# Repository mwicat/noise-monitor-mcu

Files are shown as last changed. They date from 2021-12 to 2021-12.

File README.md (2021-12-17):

# Noise level monitor using ESP8266 and InfluxDB

For server-side part of this project, see [noise-monitor-infra](https://github.com/mwicat/noise-monitor-infra)

<figure>
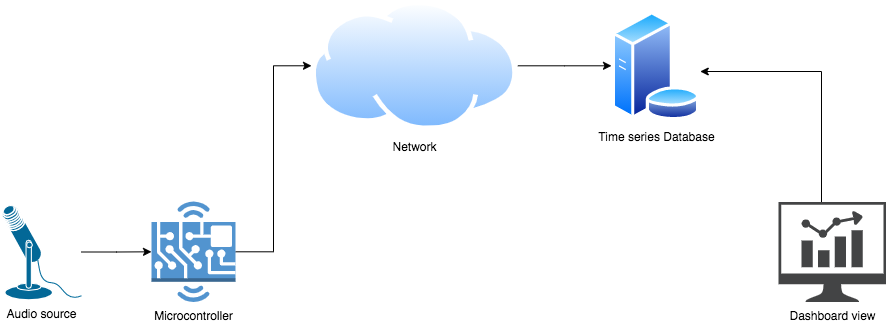
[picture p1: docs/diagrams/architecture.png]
High-level architecture

<figcaption>High-level architecture</figcaption>
</figure>

## How it works

- Monitors line level audio signal on TRS jack socket
- Transforms audio signal into volume envelope signal with
[Envelope detector circuit](https://en.wikipedia.org/wiki/Envelope_detector)
- [ESP8266 microcontroller](https://en.wikipedia.org/wiki/ESP8266) samples
envelope signal on analog input pin `A0`
- Visualises volume envelope by modulating blue LED brightness with PWM signal
on digital pin `D6`
- Converts amplitude to dB volume and sends to remote InfluxDB service
via Wi-fi connection
- On every successful write to InfluxDB service, the green LED connected to
digital pin `D5` will blink

<figure>
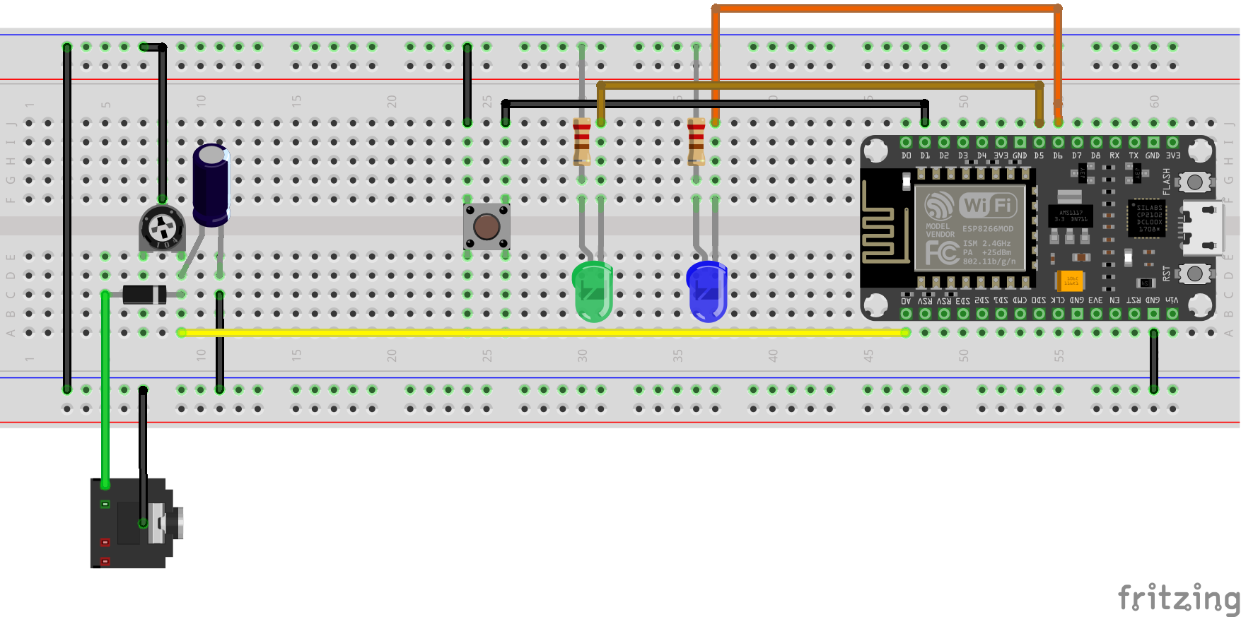
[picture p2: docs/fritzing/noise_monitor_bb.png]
Breadboard project

<figcaption>Breadboard project</figcaption>
</figure>

<figure>
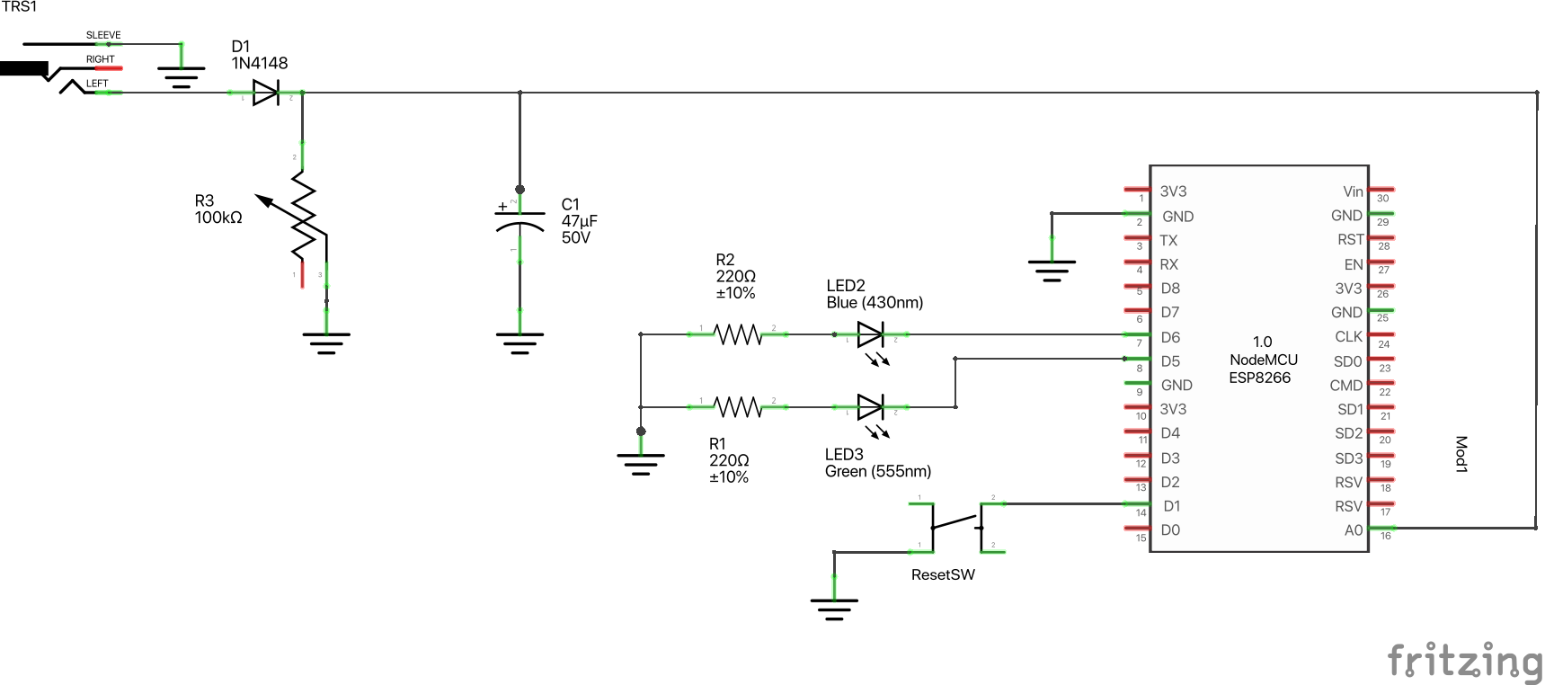
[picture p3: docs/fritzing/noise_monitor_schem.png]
Circuit schematic

<figcaption>Circuit schematic</figcaption>
</figure>

## Usage

1. Deploy attached firmware code to your MCU (project format is PlatformIO).
2. On first run MCU will start wireless access point with SSID 
3. Connect to wireless network `NoiseMonitorAP`. Default password is set
by `AP_PASSWORD` macro to `ohmynoize`
4. [Captive portal](https://en.wikipedia.org/wiki/Captive_portal) should appear
where you can configure credentials for Wi-fi that MCU should ultimately connect
to. Also specify settings for InfluxDB connection. For more details on how this
phase works or how it should work, see [WiFiManager documentation](https://github.com/tzapu/WiFiManager/blob/master/README.md#how-it-works)
5. After MCU successfuly connects to target Wi-fi network, captive portal
should disappear and builtin LED should light up
6. You can now connect audio to TRS socket. You can use headphone output
from your laptop or line out from [preamplifier](https://en.wikipedia.org/wiki/Microphone_preamplifier).
In my case I used line/headphone out from [Tascam DR-22WL
](https://www.tascam.eu/en/dr-22wl) handheld recorder.

<figure>
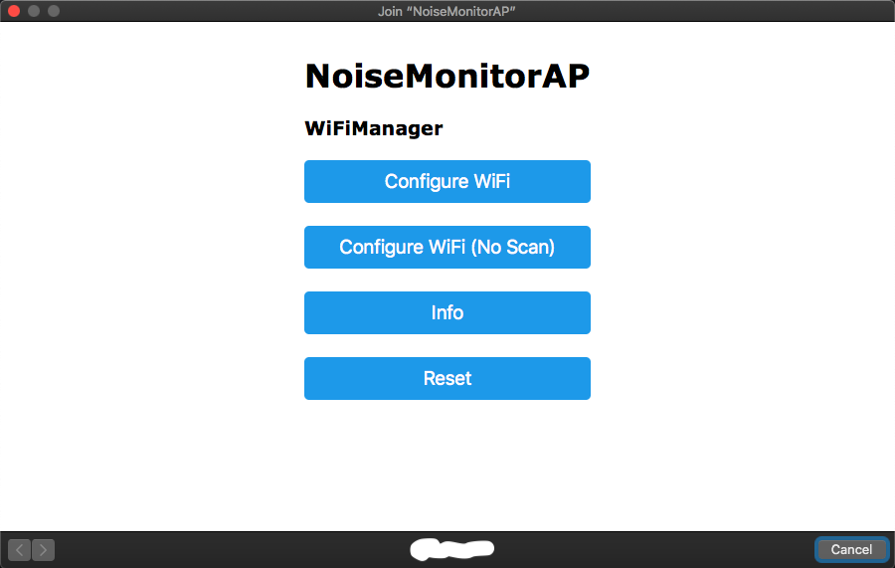
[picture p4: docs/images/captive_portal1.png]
Captive portal 1st step

<figcaption>Captive portal 1st step</figcaption>
</figure>

<figure>
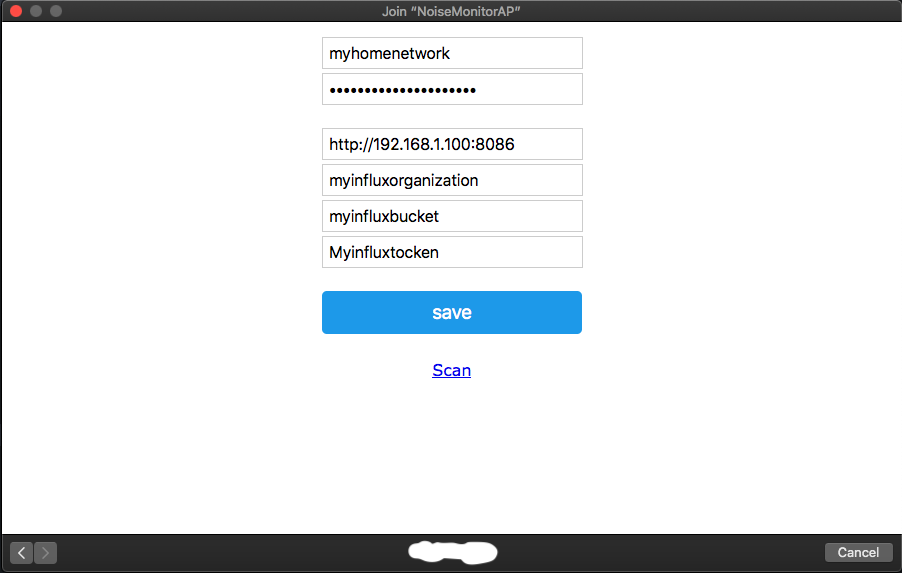
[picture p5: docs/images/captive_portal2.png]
Captive portal 2nd step

<figcaption>Captive portal 2nd step</figcaption>
</figure>

## Resetting credentials and settings

If you want MCU to forget credentials and settings that you provided and
eventually spawn again wireless AP and enter the settings again, you can
use reset switch which connects D1 pin to ground. Just restart the board and
hold the reset switch (or shorten D1 pin to ground) while it boots. In this
case, firmware should clear its memory.

## In action

<figure>
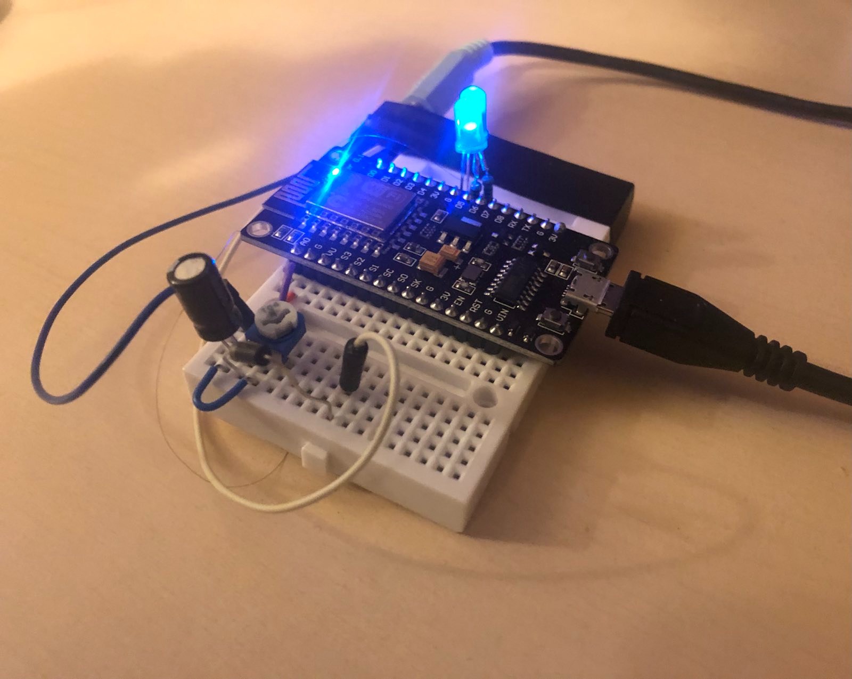
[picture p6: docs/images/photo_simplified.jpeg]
Simplified realization

<figcaption>Simplified realization</figcaption>
</figure>

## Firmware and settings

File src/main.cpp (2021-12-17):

#include <Arduino.h>
#include <EEPROM.h>
#include <ESP8266WiFi.h>
#include <WiFiManager.h>
#include <InfluxDbClient.h>

#define SENSOR_MAX_VAL 1024
#define MOMENTARY_LED_DUR 200
#define EEPROM_LEN 512

#define AP_SSID "NoiseMonitorAP"
#define AP_PASSWORD "ohmynoize"

#define MEASUREMENT_NAME "noise_level"

WiFiManager wifiManager;

InfluxDBClient client;
Point sensor(MEASUREMENT_NAME);

// lit when setup() done
static const int successConnectLedPin = LED_BUILTIN;

// lit on successful write, unlit otherwise
static const int successWriteLedPin = D5;

// lit when sensor value exceeded threshold 
static const int sensorLedPin = D6;
int sensorLedThreshold = 20;

// analog read measurements
static const int sensorInPin = A0;

// short this pin to ground if you want to reset the settings
static const int resetSettingsPin = D1;

int sensorProcessThreshold = 3;

int sensorLedValue;
int sensorValue = 0;
float dbValue = 0;

unsigned long currMillis = 0;
unsigned long msLastWriteLedOn  = 0; 
unsigned long msLastWrite = 0;
unsigned long writeInterval = 2000;

bool shouldSaveConfig = false;

char influxdb_url[128];
char influxdb_org[64];
char influxdb_bucket[64];
char influxdb_token[64];


void saveConfigCallback () {
  shouldSaveConfig = true;
}


void writeEEPROM() {
    int offset = 0;

    EEPROM.put(offset, influxdb_url);
    offset += sizeof(influxdb_url);
    EEPROM.put(offset, influxdb_org);
    offset += sizeof(influxdb_org);
    EEPROM.put(offset, influxdb_bucket);
    offset += sizeof(influxdb_bucket);
    EEPROM.put(offset, influxdb_token);
    offset += sizeof(influxdb_token);
    
    EEPROM.commit();
}


void readEEPROM() {
    int offset = 0;

    EEPROM.get(offset, influxdb_url);
    offset += sizeof(influxdb_url);
    EEPROM.get(offset, influxdb_org);
    offset += sizeof(influxdb_org);
    EEPROM.get(offset, influxdb_bucket);
    offset += sizeof(influxdb_bucket);
    EEPROM.get(offset, influxdb_token);
    offset += sizeof(influxdb_token); 
}


void clearEEPROM() {
  	for (int i = 0 ; i < EEPROM_LEN ; i++) {
	    EEPROM.write(i, 0);
	  }
    EEPROM.commit();
}

void resetSettings() {
    WiFi.mode(WIFI_STA);  // Needed to apply changes
    WiFi.disconnect(true);  // Forget connection and hopefuly credentials
    WiFi.begin("xxx", "xxx");  // Make sure credentials are scrambled in the end
    clearEEPROM();
    delay(100);
}


void setup() {
  pinMode(successConnectLedPin, OUTPUT);
  pinMode(sensorLedPin, OUTPUT);
  pinMode(successWriteLedPin, OUTPUT);
  pinMode(resetSettingsPin, INPUT_PULLUP);

  digitalWrite(successConnectLedPin, HIGH);

  bool resetOn = (digitalRead(resetSettingsPin) == LOW);

  Serial.begin(115200);
  EEPROM.begin(EEPROM_LEN);

  delay(100);

  if (resetOn) {
    resetSettings();
  }

  WiFiManagerParameter param_influxdb_url(
    "influxdb_url", "InfluxDB url", influxdb_url, 64);
  WiFiManagerParameter param_influxdb_org(
    "influxdb_org", "InfluxDB org", influxdb_org, 32);
  WiFiManagerParameter param_influxdb_bucket(
    "influxdb_bucket", "InfluxDB bucket", influxdb_bucket, 32);
  WiFiManagerParameter param_influxdb_token(
    "influxdb_token", "InfluxDB token", influxdb_token, 32);

  wifiManager.addParameter(&param_influxdb_url);
  wifiManager.addParameter(&param_influxdb_org);
  wifiManager.addParameter(&param_influxdb_bucket);
  wifiManager.addParameter(&param_influxdb_token);
  
  wifiManager.setSaveConfigCallback(saveConfigCallback);

  if (!wifiManager.autoConnect(AP_SSID, AP_PASSWORD)) {
    Serial.println("failed to connect and hit timeout");
    delay(3000);
    ESP.restart();  // reset and try again
  }

  Serial.println("local ip");
  Serial.println(WiFi.localIP());

  if (shouldSaveConfig) {
    strcpy(influxdb_url, param_influxdb_url.getValue());
    strcpy(influxdb_org, param_influxdb_org.getValue());
    strcpy(influxdb_bucket, param_influxdb_bucket.getValue());
    strcpy(influxdb_token, param_influxdb_token.getValue());
    writeEEPROM();
  } else {
    readEEPROM();
  }

  EEPROM.end();

  client.setConnectionParams(
    influxdb_url, influxdb_org, influxdb_bucket, influxdb_token);

  digitalWrite(successConnectLedPin, LOW);
}


double getdBValue(int sensorValue) {
 // Always interpret low read as minimum dB noise
  if (sensorValue == 0) {
    return -120.0;
  } else {
    return 20 * log10((float)sensorValue / SENSOR_MAX_VAL);    
  }
}

bool sendMeasurement(double dbValue) {
    sensor.clearFields();
    sensor.addField("volume", dbValue);

    bool success = client.writePoint(sensor);

    if (!success) {
      Serial.print("InfluxDB write failed: ");
      Serial.println(client.getLastErrorMessage());
    }
    return success;
}


void loop() {
  currMillis = millis();
  sensorValue = analogRead(sensorInPin);
  dbValue = getdBValue(sensorValue);

  sensorLedValue = map(sensorValue, 0, SENSOR_MAX_VAL, 0, 255);
  analogWrite(sensorLedPin, sensorLedValue);

  if (currMillis - msLastWriteLedOn > MOMENTARY_LED_DUR) {
    digitalWrite(successWriteLedPin, LOW);
  }
 
  // Don't bother processing low values
  if (sensorValue <= sensorProcessThreshold) {
    return;
  }

  if (currMillis - msLastWrite > writeInterval) {
    Serial.printf("Writing amplitude %.2g dB\n", dbValue);
    msLastWrite = currMillis;

    int status = WiFi.status();

    if (status != WL_CONNECTED) {
      Serial.printf("Wifi connection lost, status: %d\n", status);
    }

    bool sendSuccess = sendMeasurement(dbValue);

    if (sendSuccess) {
        digitalWrite(successWriteLedPin, HIGH);
        msLastWriteLedOn = currMillis;
    }
  }
  delay(100);
}

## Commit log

2021-12-17 Add base docs
    [noise_monitor.fzz]
2021-12-17 Fix redeclaration of param_influxdb_token
    [main.cpp]
